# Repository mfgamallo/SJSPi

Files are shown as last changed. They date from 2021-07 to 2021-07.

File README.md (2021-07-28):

# SJSPi
Send signals to a Sinclair joystick port from a Raspberry Pi.

The Spectrum +2A and +3 come with two special joystick ports. They look like Atari, but aren't.

This projects presents a board and some code so any gamepad usable in a Raspberry Pi can be used to drive those ports.

Make it work:

$ cd python
$ python3 -m venv ./venv
$ . ./venv/bin/activate
$ pip3 install evdev
$ pip3 install rpi.gpio
$ python3 main.py

To make it autostart on the Pi:

Clone project in /home/pi/SJSPi
Use sjspi.service to install systemd service

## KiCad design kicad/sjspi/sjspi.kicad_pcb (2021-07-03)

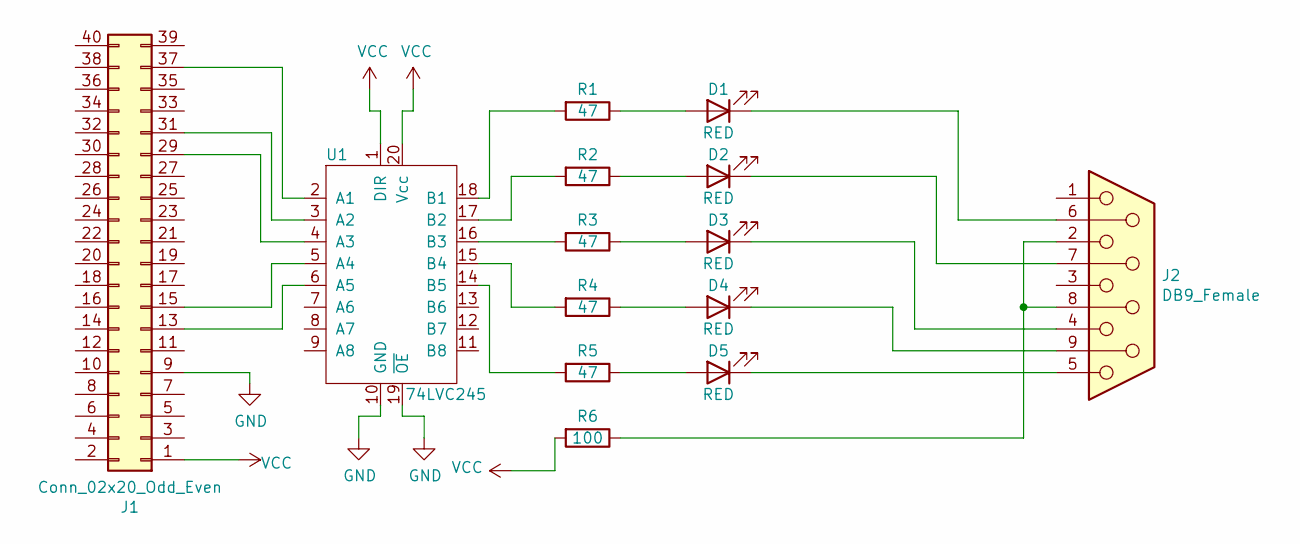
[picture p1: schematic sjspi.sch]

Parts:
D1, D2, D3, D4, D5: RED; LED_D5.0mm
J1: Conn_02x20_Odd_Even; PinSocket_2x20_P2.54mm_Vertical
J2: DB9_Female; DSUB-9_Female_Horizontal_P2.77x2.84mm_EdgePinOffset7.70mm_H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
R1, R2, R3, R4, R5: 47; R_Axial_DIN0309_L9.0mm_D3.2mm_P12.70mm_Horizontal
R6: 100; R_Axial_DIN0309_L9.0mm_D3.2mm_P12.70mm_Horizontal
U1: 74LVC245; DIP-20_W7.62mm

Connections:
GND: J1.9, U1.10 (GND), U1.19 (~OE)
unnamed: D1.1 (K), J2.6
unnamed: D1.2 (A), R1.1
unnamed: D2.1 (K), J2.7
unnamed: D2.2 (A), R2.1
unnamed: D3.1 (K), J2.4
unnamed: D3.2 (A), R3.1
unnamed: D4.1 (K), J2.9
unnamed: D4.2 (A), R4.1
unnamed: D5.1 (K), J2.5
unnamed: D5.2 (A), R5.1
unnamed: J1.13, U1.6 (A5)
unnamed: J1.15, U1.5 (A4)
unnamed: J1.29, U1.4 (A3)
unnamed: J1.31, U1.3 (A2)
unnamed: J1.37, U1.2 (A1)
unnamed: J2.2, J2.8, R6.1
unnamed: R1.2, U1.18 (B1)
unnamed: R2.2, U1.17 (B2)
unnamed: R3.2, U1.16 (B3)
unnamed: R4.2, U1.15 (B4)
unnamed: R5.2, U1.14 (B5)
VCC: J1.1, R6.2, U1.1 (DIR), U1.20 (Vcc)

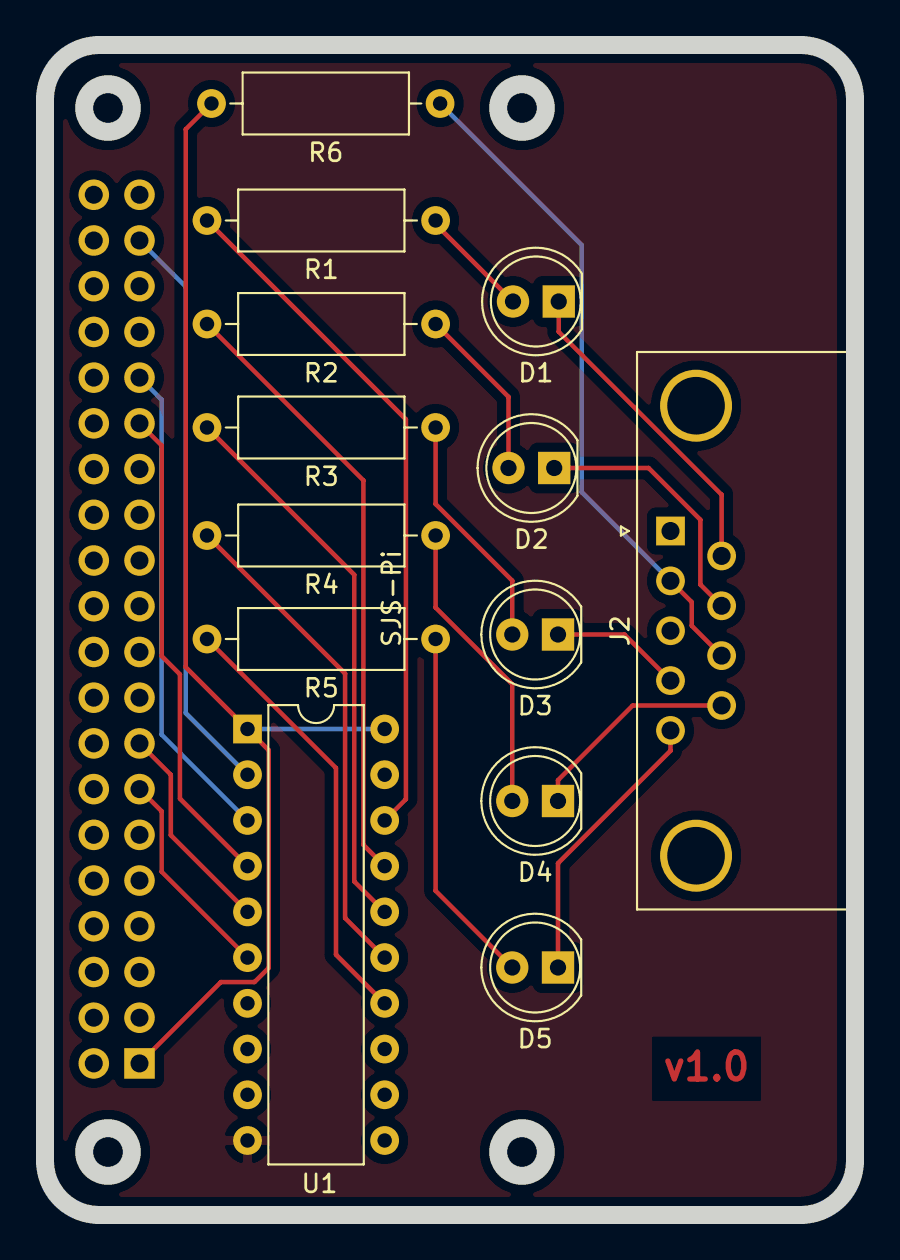
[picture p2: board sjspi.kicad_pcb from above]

Board: 2 copper layers, 45.0 x 65.0 mm, 14 parts (1 on the bottom side), 23 nets.

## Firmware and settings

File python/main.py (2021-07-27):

#!/usr/bin/env python3
"""
Reads joystick and manages GPIO pins to send old style joystick signals (Sinclair or Atari)

Currently uses just one Sinclair joystick
"""
import getopt
import sys
import traceback

import joy

def main(argv):
    try:
        opts, args = getopt.getopt(argv, "m", [])
    except getopt.GetoptError:
        print ('usage: main.py [-m]')
        sys.exit(2)

    mock_gpio = False
    for opt, arg in opts:
      if opt == '-m':
          mock_gpio = True
          
    print("Spectrum Joystick start")

    if mock_gpio:
        from gpio_mock import GpioMock
        gpio = GpioMock()
    else:
        from gpio import Gpio
        gpio = Gpio()

    while True:
        spect_joy = joy.get_joystick(gpio)
        try:
            spect_joy.loop()
        except Exception as e:
            exc_type, exc_value, exc_traceback = sys.exc_info()            
            print("Oops - error: ", e)
            traceback.print_exception(exc_type, exc_value, exc_traceback)

    print("Spectrum Joystick end")

if __name__ == "__main__":
    main(sys.argv[1:])

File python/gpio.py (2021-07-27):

"""
Concentrates all interaction with rhe Raspberry PI GPIO interface
"""
from RPi import GPIO
from joy import State

class Gpio:
    
    PI_UP = 13
    PI_DOWN = 15
    PI_LEFT = 31
    PI_RIGHT = 37
    PI_FIRE = 29

    def __init__(self):
        self.state = State()

        GPIO.setmode(GPIO.BOARD)

        GPIO.setup(Gpio.PI_UP, GPIO.OUT)
        GPIO.setup(Gpio.PI_DOWN, GPIO.OUT)
        GPIO.setup(Gpio.PI_LEFT, GPIO.OUT)
        GPIO.setup(Gpio.PI_RIGHT, GPIO.OUT)
        GPIO.setup(Gpio.PI_FIRE, GPIO.OUT)

        GPIO.output(Gpio.PI_UP, GPIO.LOW)
        GPIO.output(Gpio.PI_DOWN, GPIO.LOW)
        GPIO.output(Gpio.PI_LEFT, GPIO.LOW)
        GPIO.output(Gpio.PI_RIGHT, GPIO.LOW)
        GPIO.output(Gpio.PI_FIRE, GPIO.LOW)

    def update(self, new_state):
        if self.state.up != new_state.up:
            if new_state.up:
                GPIO.output(Gpio.PI_UP, GPIO.HIGH)
            else:
                GPIO.output(Gpio.PI_UP, GPIO.LOW)
        if self.state.down != new_state.down:
            if new_state.down:
                GPIO.output(Gpio.PI_DOWN, GPIO.HIGH)
            else:
                GPIO.output(Gpio.PI_DOWN, GPIO.LOW)
        if self.state.left != new_state.left:
            if new_state.left:
                GPIO.output(Gpio.PI_LEFT, GPIO.HIGH)
            else:
                GPIO.output(Gpio.PI_LEFT, GPIO.LOW)
        if self.state.right != new_state.right:
            if new_state.right:
                GPIO.output(Gpio.PI_RIGHT, GPIO.HIGH)
            else:
                GPIO.output(Gpio.PI_RIGHT, GPIO.LOW)
        if self.state.fire != new_state.fire:
            if new_state.fire:
                GPIO.output(Gpio.PI_FIRE, GPIO.HIGH)
            else:
                GPIO.output(Gpio.PI_FIRE, GPIO.LOW)
        self.state = new_state

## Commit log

2021-06-12 PCB v0.1
    [sjspi-B_Cu.gbl, sjspi-B_Mask.gbs, sjspi-B_SilkS.gbo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]
2021-06-21 v0.2 - fix pi connector position. Fix DB9 size. Connect level shifter's ground leg
    [sjspi-B_Cu.gbl, sjspi-B_Mask.gbs, sjspi-B_SilkS.gbo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]
2021-06-27 v0.3 - fix resistors values
    [sjspi-B_Cu.gbl, sjspi-B_Mask.gbs, sjspi-B_SilkS.gbo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]
2021-07-03 v1.0 - Release
    [sjspi-B_Cu.gbl, sjspi-B_Mask.gbs, sjspi-B_SilkS.gbo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]
2021-07-27 Fix error. Improve readme
    [gpio.py]

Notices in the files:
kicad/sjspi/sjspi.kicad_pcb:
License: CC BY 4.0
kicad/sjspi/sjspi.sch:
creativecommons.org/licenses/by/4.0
